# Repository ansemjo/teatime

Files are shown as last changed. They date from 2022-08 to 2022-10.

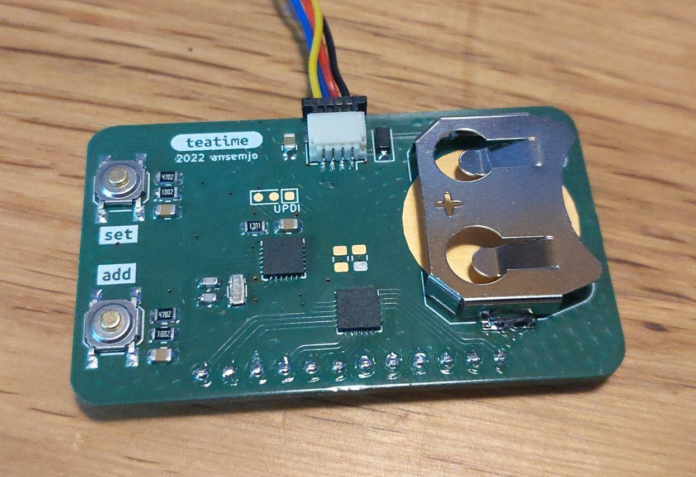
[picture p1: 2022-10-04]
images/assembled.jpg

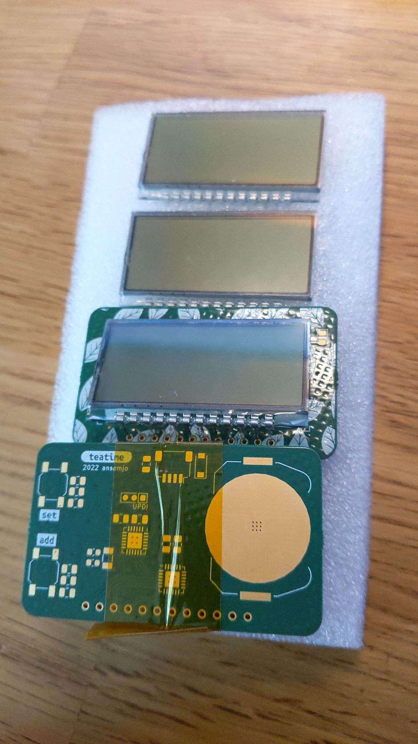
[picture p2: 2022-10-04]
images/firstbatch.jpg

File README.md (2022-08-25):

# Readme

## Notes on the question of voltage regulation

* There's only two components that are somewhat relevant in terms of voltage:
  * the ATtiny; handles 1.7–5.5V per datasheet
  * the LCD; wants 3V per datasheet
* Many of the similar LCD modules are advertised as 3.0–5V compatible.
  * [GoodDisplay's own precautions say that overvoltage will (merely) "shorten its life"](https://www.good-display.com/news/102.html)
  * [Another explainer says that overvoltage usually (only) results in ghosting](https://focuslcds.com/journals/lcd-voltage-inputs-for-lcd-displays-explained/)
* I'll have a diode behind the battery to prevent charging the coin cell in any case.
* The LCD is driven directly by the ATtiny IO pins, so *if* I want to regulate ... I'll need to regulate the input voltage to the ATtiny.
* The ATtiny pins can only handle about VDD + 0.5V, so I'll need either:
  * "Simple" protection with input resistors to limit the current; per § 34.2 of the datasheet it is acceptable to limit the current with $R = \frac{(V_{pin} - (VDD + 0.6))}{I_{Cn}}$, where $I_{Cn} = 1 \text{mA}$
    * How does this interact with the pull-up requirement on I2C pins?
  * "Full" level shifting for any logic pins, i.e. external I2C connectors and programming ports; except UPDI can handle up to 13V regardless of VDD

* Another funky solution would be to omit the regulation and "just" stay within the ATtiny's limits. Then implement the "own voltage" sensing (which is usually used for battery voltage detection; aside: how does that work behind a diode?) to check what voltage is applied on startup. If it's more than 3.3V, use PWM modulation on the IO pins to the display to keep the average at around 3V?

## Driving the LCD

* Aha! These LCDs are so cheap because they don't include and driver electronics. And it's actually not that trivial to drive.
* You *can* apply a constant voltage but that will destroy the LCD over time through ... elctrophoresis? Either way, you need to apply AC by alternating the polarity of each segment during each frame.
* *Do* drive the commons and segments that you *don't* want to be visible, but drive them with equal voltages during both halves of the frame to keep differential at zero. But you still do need to alternate the voltage.
* There's a nice [application note by Atmel: AVR241](https://ww1.microchip.com/downloads/en/AppNotes/doc2569.pdf).
* And [an article by Pacific Display Devices](https://www.pacificdisplay.com/lcd_multiplex_drive.htm).
* And particularly useful is an [application note by ST Microelectronics: AN1447](https://www.st.com/resource/en/application_note/an1447-software-driver-for-4multiplexed-lcd-with-a-standard-st62-stmicroelectronics.pdf). It actually describes how to drive a 4-multiplexed LCD with a simple microcontroller.

## Notes on Components

### The LCD

* Ain't nobody got space for that many pins! I *really* didn't want to use a 40-pin component. Especially because I don't have any microcontrollers that have enough IO ports.
* The 12 pin variant requires time multiplexing but I'm kinda used to that from the other two display projects I built already.

### 32.768 kHz Crystal

* I [picked a crystal from the same series](https://uk.farnell.com/abracon/abs07-120-32-768khz-t/crystal-32-768khz-6pf-3-2-x-1/dp/2467864) that David Johnson-Davies used; but a (to me) more common 12.5 pF loading capacitor value.

* [Per an Electronics StackExchange post](https://electronics.stackexchange.com/questions/39103/selecting-loading-capacitor-values-for-32-khz-crystal), the formula to select (two identical) loading capacitors $C$ is $C_{load} = \frac{C}{2} + C_{parasitic}$, where the parasitic capacitance of the PCB is usually assumed to be around 2.5 pF. Rearranging for the "unknown" yields $C = 2\cdot(C_{load} - C_{parasitic})$ and with $C_{load} = 12.5\,pF$ this gives $C \approx 20\,pF$.
* I chose to use 0603 capacitors because this is a new part in my personal stock, I feel very confident soldering smaller parts than 0805 by now and I'll probably only ever use these capacitors in this exact combination.

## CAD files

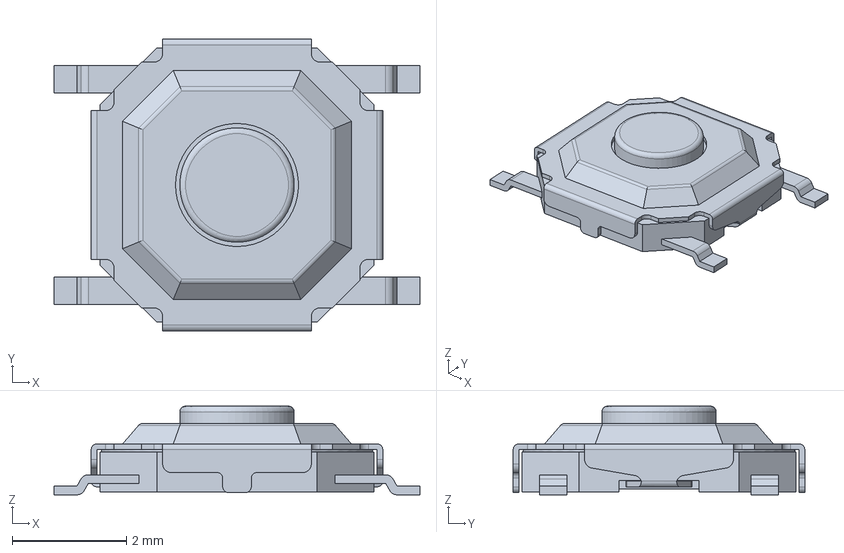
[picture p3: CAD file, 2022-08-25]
hardware/local_library/PTS526SPG15SMTR2LFS.stp
6.40 x 5.10 x 1.55 mm

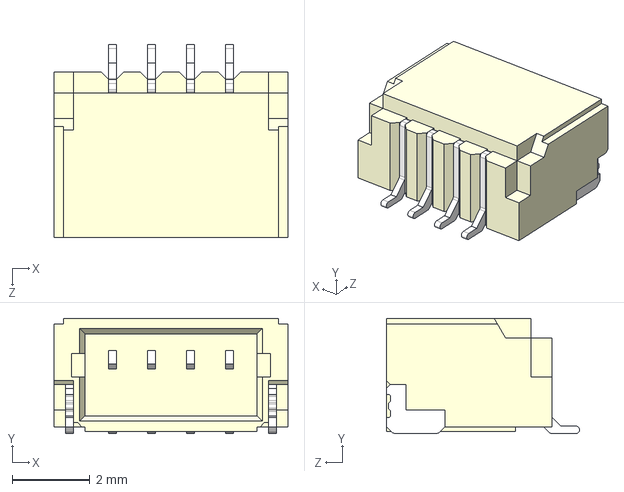
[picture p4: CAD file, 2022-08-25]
hardware/local_library/SM04B-SRSS-TB(LF)(SN)--3DModel-STEP-56544.stp
6.00 x 2.96 x 4.95 mm

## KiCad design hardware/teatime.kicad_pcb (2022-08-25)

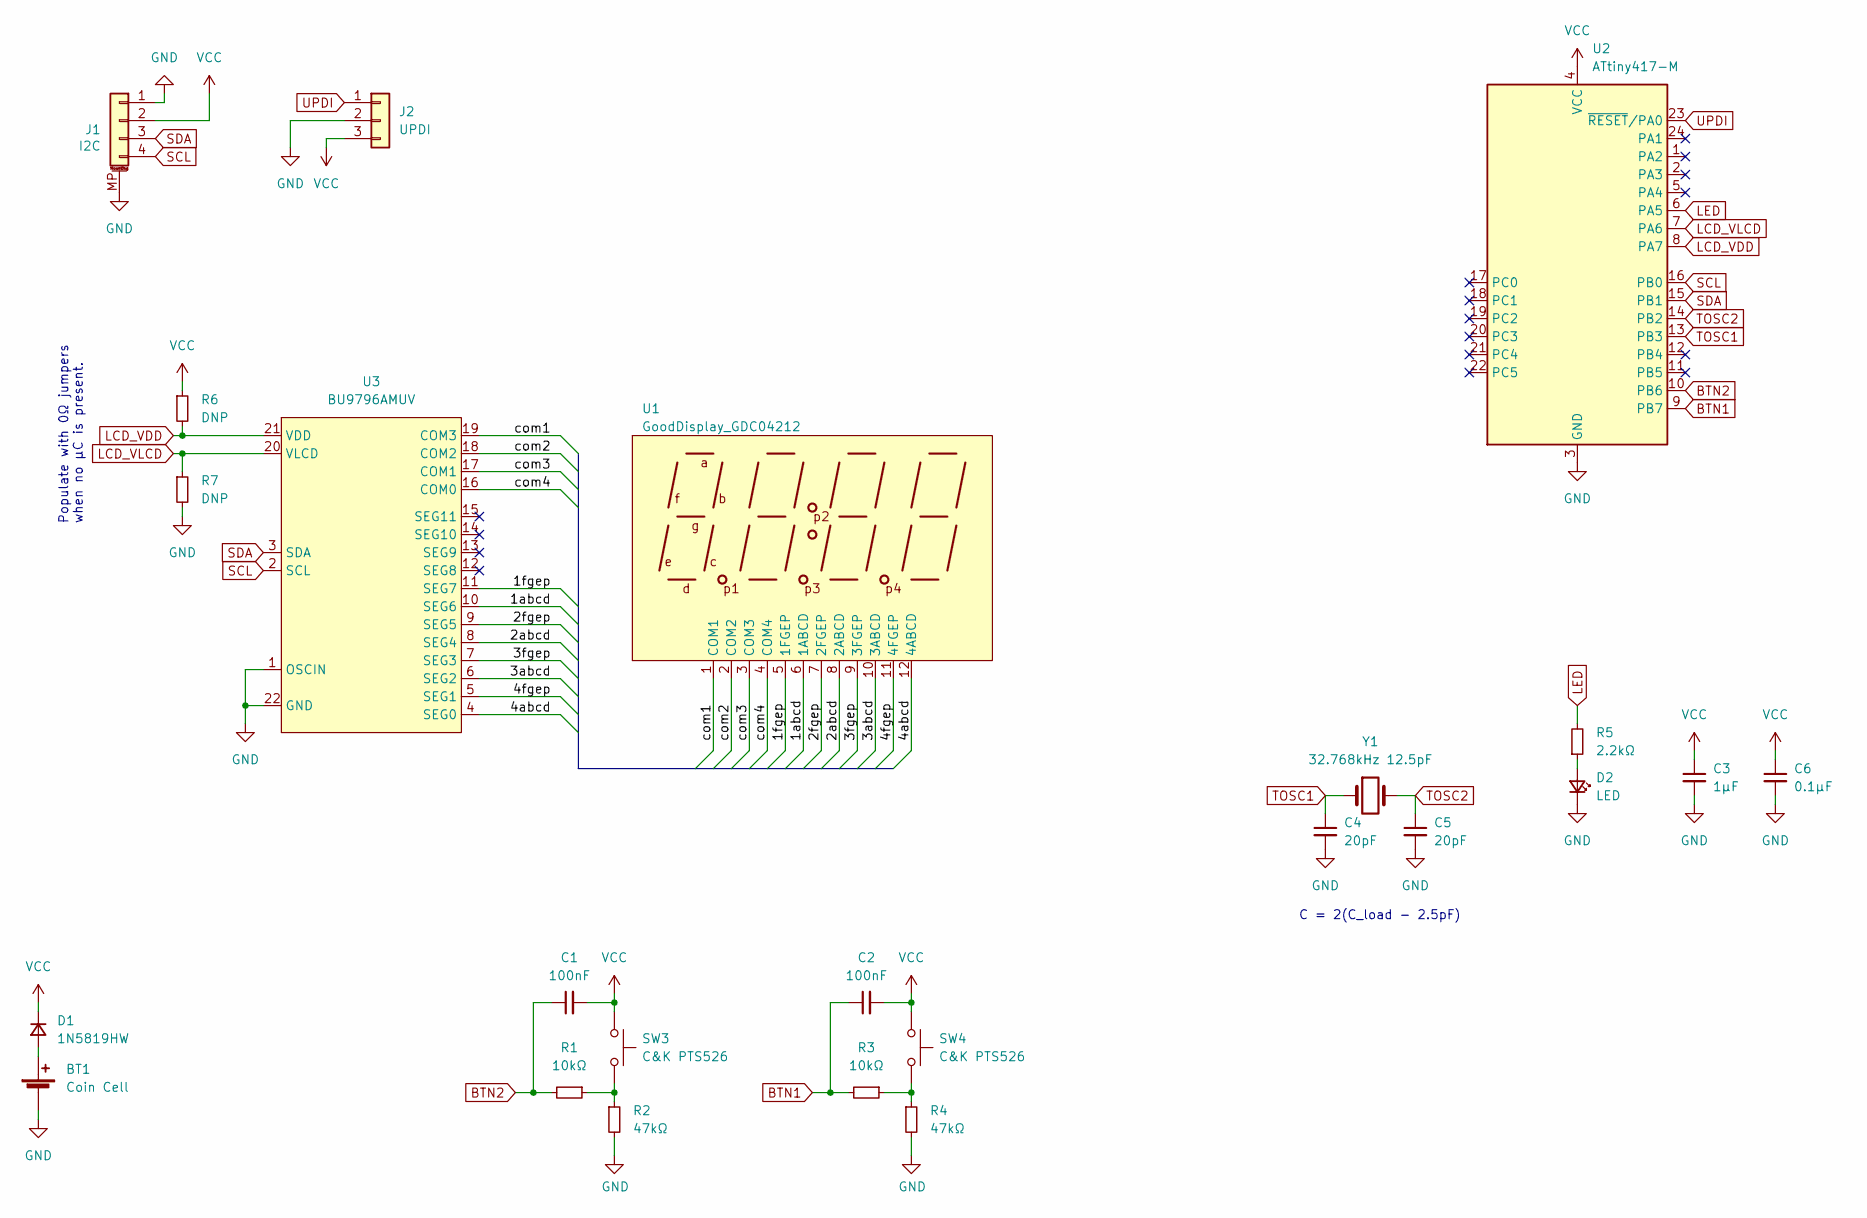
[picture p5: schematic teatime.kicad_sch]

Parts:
BT1: Coin Cell; BatteryHolder_Keystone_3034_1x20mm
C1, C2: 100nF; C_0805_2012Metric
C3: 1µF; C_0805_2012Metric
C4, C5: 20pF; C_0603_1608Metric
C6: 0.1µF; C_0805_2012Metric
D1: 1N5819HW; D_SOD-123
D2: LED; LED_0805_2012Metric
J1: I2C; JST_SH_SM04B-SRSS-TB_1x04-1MP_P1.00mm_Horizontal
J2: UPDI; UPDI_PogoProg
R1, R3: 10kΩ; R_0805_2012Metric
R2, R4: 47kΩ; R_0805_2012Metric
R5: 2.2kΩ; R_0805_2012Metric
R6, R7: DNP; R_0805_2012Metric
SW3, SW4: C&K PTS526; SW_SPST_SKQG_WithStem
U1: GoodDisplay_GDC04212; LCD-12PIN
U2: ATtiny417-M; QFN-24-1EP_4x4mm_P0.5mm_EP2.6x2.6mm
U3: BU9796AMUV; VQFN-24-1EP_4x4mm_P0.5mm_EP2.45x2.45mm
Y1: 32.768kHz 12.5pF; Crystal_SMD_3215-2Pin_3.2x1.5mm

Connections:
/1abcd: U1.6 (1ABCD), U3.10 (SEG6)
/1fgep: U1.5 (1FGEP), U3.11 (SEG7)
/2abcd: U1.8 (2ABCD), U3.8 (SEG4)
/2fgep: U1.7 (2FGEP), U3.9 (SEG5)
/3abcd: U1.10 (3ABCD), U3.6 (SEG2)
/3fgep: U1.9 (3FGEP), U3.7 (SEG3)
/4abcd: U1.12 (4ABCD), U3.4 (SEG0)
/4fgep: U1.11 (4FGEP), U3.5 (SEG1)
/com1: U1.1 (COM1), U3.19 (COM3)
/com2: U1.2 (COM2), U3.18 (COM2)
/com3: U1.3 (COM3), U3.17 (COM1)
/com4: U1.4 (COM4), U3.16 (COM0)
BTN1: C2.1, R3.2, U2.9 (PB7)
BTN2: C1.1, R1.2, U2.10 (PB6)
GND: BT1.2 (-), C3.2, C4.2, C5.2, C6.2, D2.1 (K), J1.1, J1.MP (MountPin), J2.2, R2.2, R4.2, R7.2, U2.3 (GND), U2.25 (GND), U3.1 (OSCIN), U3.22 (GND), U3.23 (TEST1), U3.24 (TEST2), U3.25 (EXT-PAD)
LCD_VDD: R6.2, U2.8 (PA7), U3.21 (VDD)
LCD_VLCD: R7.1, U2.7 (PA6), U3.20 (VLCD)
LED: R5.2, U2.6 (PA5)
unnamed: BT1.1 (+), D1.2 (A)
unnamed: D2.2 (A), R5.1
unnamed: R1.1, R2.1, SW3.2
unnamed: R3.1, R4.1, SW4.2
SCL: J1.4, U2.16 (PB0), U3.2 (SCL)
SDA: J1.3, U2.15 (PB1), U3.3 (SDA)
TOSC1: C4.1, U2.13 (PB3), Y1.1
TOSC2: C5.1, U2.14 (PB2), Y1.2
UPDI: J2.1, U2.23 (~RESET/PA0)
VCC: C1.2, C2.2, C3.1, C6.1, D1.1 (K), J1.2, J2.3, R6.1, SW3.1, SW4.1, U2.4 (VCC)

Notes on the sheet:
Populate with 0Ω jumpers when no µC is present.
C = 2(C_load - 2.5pF)

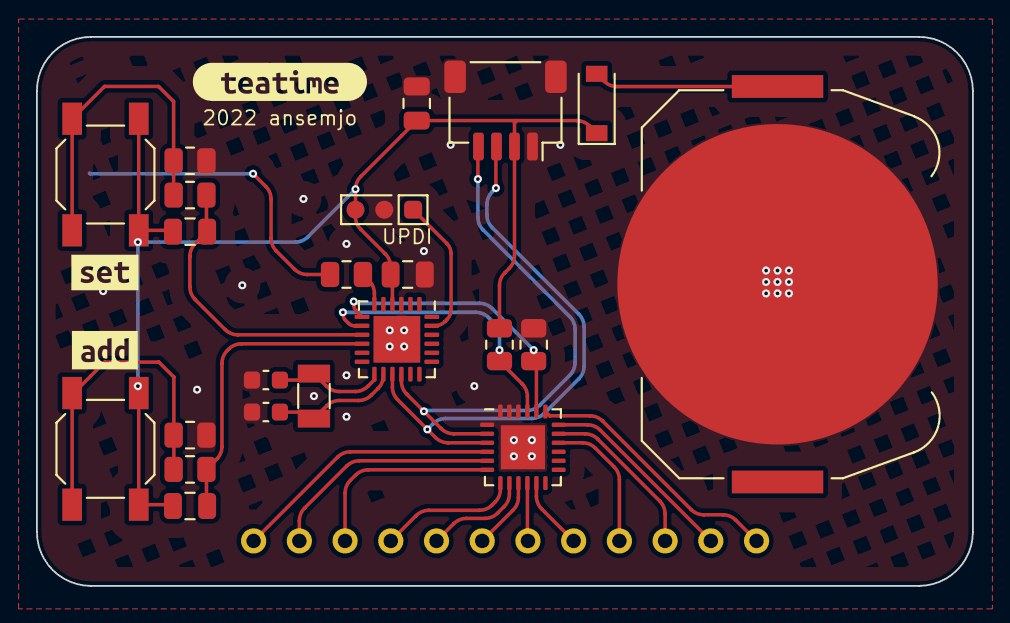
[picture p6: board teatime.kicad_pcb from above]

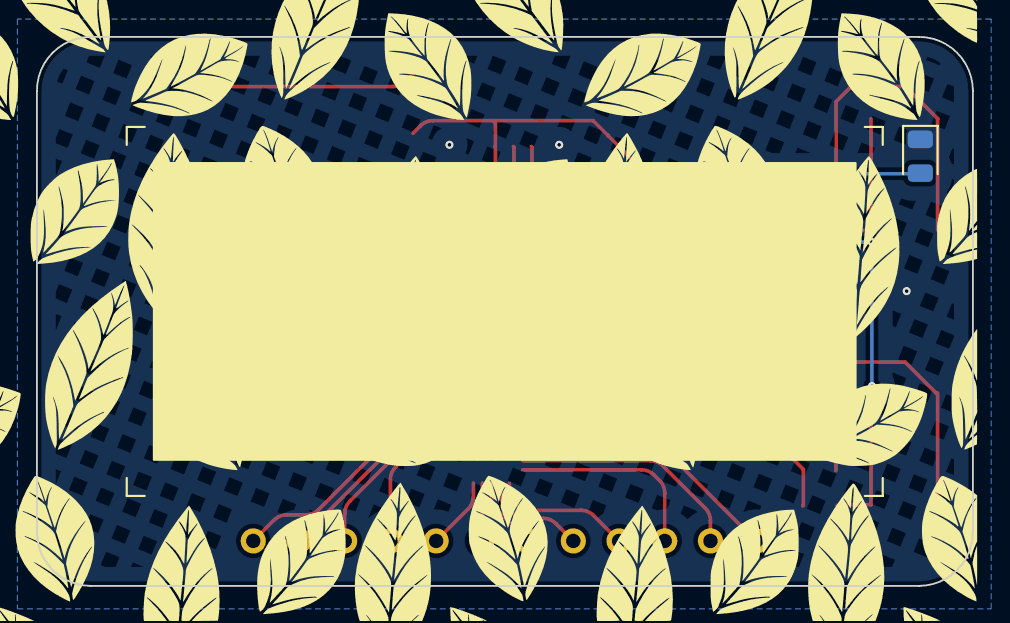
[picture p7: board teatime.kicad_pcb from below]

Board: 2 copper layers, 52.0 x 30.5 mm, 27 parts (2 on the bottom side), 28 nets.

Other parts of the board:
kibuzzard-6305512F: G***; kibuzzard-6305512F
kibuzzard-63055090: G***; kibuzzard-63055090
kibuzzard-63055120: G***; kibuzzard-63055120

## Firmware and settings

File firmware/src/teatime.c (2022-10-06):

// teatime - Simple LCD Timer board
// Copyright (c) 2022 Anton Semjonov
// Licensed under the MIT License

#include <avr/io.h>
#include <avr/interrupt.h>
#include <avr/delay.h>
#include <avr/sleep.h>

#include "oscillators.h"
#include "sleepmode.h"
#include "lcddriver.h"
#include "segments.h"
#include "lcddriver.h"
#include "i2c_controller.h"
#include "ports.h"
#include "led.h"

// counters for button press duration
volatile uint8_t btn_add_count = 0;
volatile bool    btn_add_was_long = false;
volatile uint8_t btn_set_count = 0;
volatile bool    btn_set_was_long = false;

// how many ticks for a long press
const int long_len = 32;

// "state machine"
typedef enum {
  idle = 0,
  running,
  paused,
  finished,
} teatime_state;
volatile teatime_state state = idle;

// mini buffer for lcd commands
uint8_t lcd_commands[3] = { 0x00, 0x00, 0x00 };

// set countdown value
volatile uint16_t countdown_preset = 0;
volatile uint16_t countdown = 0;
volatile uint16_t rtc_value = 0;

/**
 * State machine with button presses:
 * (×btn = short press, |btn = long press)
 * 
 * [0] "00:00" set time
 *    ×add --> + 10 seconds
 *    |add --> + 1 minute (+ hold)
 *    ×set --> [1] running, store countdown value as preset
 * 
 * [1] running, time runs down, switch to [2] end on zero
 *    ×add, |add --> as [0], but not added to preset
 *    ×set --> pause/unpause
 * 
 * [2] end, led and display is blinking
 *    ×set --> reset to [0] with previously preset time
 * 
**/

void button_add() {
  if (!(pressed_add)) {
    // long press handled in tick()
    if (state != finished) {
      if (!btn_add_was_long) countdown += 10;
      if (countdown >= 6000) countdown = 5999;
    }
    btn_add_count = 0;
    btn_add_was_long = false;
  }
}

void button_set() {
  if (pressed_set) {

    switch (state) {
      case idle:
        if (countdown == 0) {
          led_toggle();
          break;
        }
        countdown_preset = countdown;
        run_rtc(1);
        state = running;
        break;

      case running:
        rtc_value = halt_rtc();
        lcd_commands[0] = LCD_BLKCTL_cmd | LCD_BLKCTL_1Hz;
        i2c_write(LCD_ADDRESS, lcd_commands, 1);
        state = paused;
        break;

      case paused:
        run_rtc(rtc_value);
        lcd_commands[0] = LCD_BLKCTL_cmd | LCD_BLKCTL_off;
        i2c_write(LCD_ADDRESS, lcd_commands, 1);
        state = running;
        break;

      case finished:
        countdown = countdown_preset;
        lcd_commands[0] = LCD_BLKCTL_cmd | LCD_BLKCTL_off;
        i2c_write(LCD_ADDRESS, lcd_commands, 1);
        led_off();
        state = idle;
        break;
      
      default:
        break;
    }
  } else {
    if (state == idle) {
      led_off();
    }
    btn_set_count = 0;
    btn_set_was_long = false;
  }
}

uint8_t mybuf[5] = {
  // turn on display from DDRAM
  LCD_MODESET_cmd | LCD_MODESET_ON | LCD_MODESET_bias_03,
  // HELO (reverse order)
  CHAR_0, CHAR_L, CHAR_E, CHAR_H,
  // 0xF5, 0x85, 0x97, 0x67,
};

// display the countdown time in 12:34 format
void display_time(uint16_t time) {
  // split into mins:secs
  uint8_t secs = time % 60;
  uint8_t mins = time / 60;
  // format seconds
  mybuf[1] = NUMBERS[ secs       % 10];
  mybuf[2] = NUMBERS[(secs / 10) % 10];
  mybuf[3] = NUMBERS[ mins       % 10] | Ap;
  mybuf[4] = NUMBERS[(mins / 10) % 10];
  // when running, blink the colon
  if ((state == running) && (secs % 2) == 1) {
    mybuf[3] &= ~Ap;
  }
  i2c_write(LCD_ADDRESS, mybuf, 5);
}


// display button interrupt counts
void tick() {
  if (pressed_add && state != finished) {
    btn_add_count++;
    if (btn_add_count >= long_len) {
      btn_add_was_long = true;
      countdown += 60;
      if (countdown >= 6000) countdown = 5999;
      btn_add_count = 0;
    }
  }
  if (pressed_set) {
    if (btn_set_count < long_len*2) {
      btn_set_count++;
    } else if (!btn_set_was_long) {
      btn_set_was_long = true;
      halt_rtc();
      countdown_preset = countdown = 0;
      lcd_commands[0] = LCD_BLKCTL_cmd | LCD_BLKCTL_off;
      i2c_write(LCD_ADDRESS, lcd_commands, 1);
      led_off();
      state = idle;
      btn_set_count = 0;
    }
  }
  display_time(countdown);
}

// count down
void second() {
  if (countdown > 0)
    countdown--;
  if (countdown == 0) {
    halt_rtc();
    state = finished;
    lcd_commands[0] = LCD_BLKCTL_cmd | LCD_BLKCTL_2Hz;
    i2c_write(LCD_ADDRESS, lcd_commands, 1);
    led_on();
  }
}

int main() {

  // setup all the things
  setup_system_clock();
  setup_crystal();
  setup_pit_ticks(RTC_PERIOD_CYC512_gc);
  setup_rtc_seconds();
  setup_led();
  setup_lcddriver();
  setup_buttons();
  sleep_configure_standby();
  sleep_enable();
  disable_unused_pins();
  sei(); // enable interrupts

  i2c_init();
  i2c_write(LCD_ADDRESS, mybuf, 5);

  i2c_wait_until_idle();
  mybuf[0] = 0x00;

  for (;;) sleep_cpu();

}

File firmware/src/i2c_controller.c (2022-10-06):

// Use 1-series TWI for I2C controller communications.
// Copyright (c) 2022 Anton Semjonov
// Licensed under the MIT License

#include "i2c_controller.h"
#include "sleepmode.h"


// ---------- init and basics ---------- //

// TODO: use a single bitfield "register"?
i2c_error i2c_result = success;

// hold current and end pointers
static volatile uint8_t *buf = NULL;
static volatile uint8_t *end = NULL;

// save the previous sleep controller state
static volatile uint8_t sleepmode = 0x00;


// configure the twi controller for interrupt-driven operation
void i2c_init() {

  #if F_SCL == 1000000L
  // enable fast mode plus (Fm+)
  TWI0.CTRLA = TWI_FMPEN_bm;
  #endif

  // set the calculated baudrate
  TWI0.MBAUD = TWI_BAUD;

  // enable peripheral in "master" mode
  TWI0.MCTRLA = \
    TWI_RIEN_bm | TWI_WIEN_bm   // enable interrupt vector
  | TWI_TIMEOUT_DISABLED_gc     // no timeout for i2c
  | TWI_ENABLE_bm;

  // force the bus state into IDLE
  TWI0.MSTATUS = TWI_BUSSTATE_IDLE_gc;

}

// begin a transaction by writing an address with direction bit
void i2c_start(uint8_t address, bool reading) {

  // write the address
  TWI0.MADDR = address << 1 | (reading ? 1 : 0);

  // configure idle sleep mode (so peripherals remain active)
  sleepmode = SLPCTRL.CTRLA;
  sleep_configure_idle();

}

// clear buffers and end a transaction "in software"
void i2c_end(i2c_error err) {

  // store transaction result and clear pointers
  i2c_result = err;
  buf = end = NULL;

  // restore previous sleep mode
  SLPCTRL.CTRLA = sleepmode;

}

// stop a transaction by generating a stop condition
void i2c_stop() {

  // generate the stop condition on the bus and wait for idle
  TWI0.MCTRLB |= TWI_MCMD_STOP_gc;
  // TODO: we don't want busy waiting in an ISR, do we?
  while (!(TWI0.MSTATUS & TWI_BUSSTATE_IDLE_gc));

}

// busy-wait for a transaction to finish
void i2c_wait_until_idle() {
  while (!(TWI0.MSTATUS & TWI_BUSSTATE_IDLE_gc));
}


// ---------- writing ---------- //

bool i2c_write(uint8_t address, const uint8_t *data, const uint8_t length) {

  // abort if another transmission is already running
  if (buf != NULL) return false;

  // also abort if bus state is not currently idle
  if (!(TWI0.MSTATUS & TWI_BUSSTATE_IDLE_gc)) return false;

  // otherwise start a transmission, store pointer and length
  buf = data;
  end = data + length;

  // write address and configure sleep mode
  i2c_start(address, false);

}

// ---------- interrupt handler ---------- //

ISR(TWI0_TWIM_vect) {

  // error: arbitration lost or bus error
  if (TWI0.MSTATUS & (TWI_ARBLOST_bm | TWI_BUSERR_bm)) {
    i2c_end(arbitration_lost);
  }

  // error: no such address
  if (TWI0.MSTATUS & TWI_RXACK_bm) {
    i2c_stop();
    i2c_end(address_nack);
  }

  // error: pointers are not set ?!
  if ((buf == NULL) || (end == NULL)) {
    return; // ?!
  }

  // WIF --> write interrupt
  if (TWI0.MSTATUS & TWI_WIF_bm) {

    // if there is data remaining ...
    if (buf < end) {

      // write next byte
      TWI0.MCTRLB = TWI_ACKACT_ACK_gc | TWI_MCMD_RECVTRANS_gc;
      TWI0.MDATA = *buf++;

    } else {

      // end the transaction
      i2c_stop();
      i2c_end(success);

    }
  }

  // RIF --> read interrupt // TODO: untested
  if (TWI0.MSTATUS & TWI_RIF_bm) {

    // if more data is to be read ...
    if (buf < end) {
      // copy the last read byte
      *buf++ = TWI0.MDATA;
    }

    // if we want to read another byte ...
    // note: this is *after* incrementing buf above
    if (buf < end) {

      // send an ACK
      TWI0.MCTRLB = TWI_ACKACT_ACK_gc | TWI_MCMD_RECVTRANS_gc;

    } else { // or if this was the last byte we want to read ...

      // send a NACK and stop
      TWI0.MCTRLB = TWI_ACKACT_NACK_gc;
      i2c_stop();
      i2c_end(success);

    }

  }

}

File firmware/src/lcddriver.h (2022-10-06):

// Rohm BU9796AFS / BU9796AMUV commands
// Copyright (c) 2022 Anton Semjonov
// Licensed under the MIT License

#pragma once

/**
 * A few example commands to drive the controller directly.
 * (Either put 0Ω resistors in R6 R7 or just set A6 LOW and A7 HIGH.)
 *
 * Reset the controller:
 * $ i2ctransfer -y 12 w1@0x3E 0x6A # 0b01101010
 *
 * Enable outputs (start displaying from DDRAM):
 * $ i2ctransfer -y 12 w1@0x3E 0x48 # 0b01001000
 *
 * Set contents to "HELO":
 * $ i2ctransfer -y 12 w5@0x3E 0x00 0xF5 0x85 0x97 0x67
 *
 * Override; all segments on:
 * $ i2ctransfer -y 12 w1@0x3E 0x7E # 0b01111110
 *
 **/

// lcd driver's i2c address
#define LCD_ADDRESS 0x3E

// there's another command in the next byte
#define CMDBIT 0b10000000

#define LCD_DISCTL_cmd 0b00100000 // display control command
#define LCD_DISCTL_framerate_80Hz 0b00 << 3 // normal mode, 80Hz framerate
#define LCD_DISCTL_framerate_71Hz 0b01 << 3 // power save 1, 71Hz framerate
#define LCD_DISCTL_framerate_64Hz 0b10 << 3 // power save 2, 64Hz framerate
#define LCD_DISCTL_framerate_50Hz 0b11 << 3 // power save 3, 50Hz framerate
#define LCD_DISCTL_waveform_lineinv  0b0 << 2 // line inversion drive waveform
#define LCD_DISCTL_waveform_frameinv 0b1 << 2 // frame inversion drive waveform
#define LCD_DISCTL_powersave_psm1 0b00 << 0 // power save mode 1 (x0.5)
#define LCD_DISCTL_powersave_psm2 0b01 << 0 // power save mode 2 (x0.67)
#define LCD_DISCTL_powersave_norm 0b10 << 0 // normal mode (x1.0)
#define LCD_DISCTL_powersave_high 0b11 << 0 // high power mode (x1.8)

#define LCD_MODESET_cmd 0b01000000 // display mode setting
#define LCD_MODESET_OFF 0b0 << 3 // display OFF
#define LCD_MODESET_ON  0b1 << 3 // display ON
#define LCD_MODESET_bias_03 0b0 << 2 // 1/3 bias
#define LCD_MODESET_bias_05 0b1 << 2 // 1/2 bias

#define LCD_ADSET_mask 0b00011111 // address setting mask before data write
#define LCD_ADSET_max  0b00010011 // maximum allowed address (19)

#define LCD_ICSET_cmd 0b01101000 // chip operation commands
#define LCD_ICSET_reset 0b1 << 1 // execute software reset
#define LCD_ICSET_osc_int 0b0 << 0 // use internal oscillator
#define LCD_ICSET_osc_ext 0b1 << 0 // use external clock input

#define LCD_BLKCTL_cmd 0b01110000 // blink control command
#define LCD_BLKCTL_off  0b00 // off, steady output
#define LCD_BLKCTL_05Hz 0b01 // blink with 0.5Hz
#define LCD_BLKCTL_1Hz  0b10 // blink with 1Hz
#define LCD_BLKCTL_2Hz  0b11 // blink with 2Hz

#define LCD_APCTL_cmd 0b01111100 // all pixel control command
#define LCD_APCTL_APON_normal  0b0 << 1 // do not force all pixels on
#define LCD_APCTL_APON_allON   0b1 << 1 // force all pixels ON
#define LCD_APCTL_APOFF_normal 0b0 << 0 // do not force all pixels off
#define LCD_APCTL_APOFF_allOFF 0b1 << 0 // force all pixels OFF


void setup_lcddriver();

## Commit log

2022-08-25 first teatime version without dedicated display controller
    [PTS526SPG15SMTR2LFS.stp, SM04B-SRSS-TB(LF)(SN)--3DModel-STEP-56544.stp, multiplexing.ods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]
2022-08-25 updated design using dedicated rohm BU9796AMUV driver
    [teatime.kicad_pcb, teatime.kicad_sch]
2022-08-25 rounded tracks
    [teatime.kicad_pcb]
2022-09-29 add link to lcd driver datasheet in schematic
    [teatime.kicad_sch]
2022-09-29 generate interactive bom for soldering
2022-09-29 move hardware files into subdirectory
    [PTS526SPG15SMTR2LFS.stp, SM04B-SRSS-TB(LF)(SN)--3DModel-STEP-56544.stp, teatime.kicad_pcb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]
2022-09-30 initialize firmware dir with platformio project
    configure system clocks and crystal and only use PIT to blink the LED,
    otherwise just go to sleep
2022-10-04 add lcd driver and segment mapping headers
    also switch down to 10 mhz cpu clock due to safe operating area at 3V
    coin cell battery voltage
    [characters.ods]
2022-10-05 implement i2c_controller to write digits to display
    it is using an interrupt-driven style to be able to save power in idle
    mode while waiting for the next packet
2022-10-06 test button filtering with pin interrupts
2022-10-06 restore previous sleep mode in i2c controller
2022-10-06 [WIP] implement an actual timer function
    this is a bit of spaghetti code but it works like I intended my teatimer
